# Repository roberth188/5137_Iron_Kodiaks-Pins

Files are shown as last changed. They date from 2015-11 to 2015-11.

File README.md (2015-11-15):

# 5137_Iron_Kodiaks-Pins
The team circuit board pins files, including both the schematic/board and Gerber files.
Contact me if you have any questions.

To order new boards, go to [dirtyPCBs](http://dirtypcbs.com/) and upload all of the Gerber files (the files that don't end in either .sch or .brd. Make sure to select 2 layer, the 5x5 cm size, the proper quantity, red color, 1.6mm thickness, ENIG Coating, no stencil, Regular processing, shipping to United States, and DHL China works very well. This will make the boards exactly like they were ordered before. 

Contact me about ordering the components - they vary considerably with what is in stock, so they will need to be found again.

Board file images were rendered with the fabulous ZofzPCB tool (available free online) and the colors were adjusted to accurately represent the ENIG plating over the pads of the red PCBS (for the team's cardinal and gold colors).

  

Yes, the trace that goes through the switch in that pad is unintentional but, as that connection is shorted, anyways, when it is turned off, it electrically has no impact. It can be safely and completely ignored.

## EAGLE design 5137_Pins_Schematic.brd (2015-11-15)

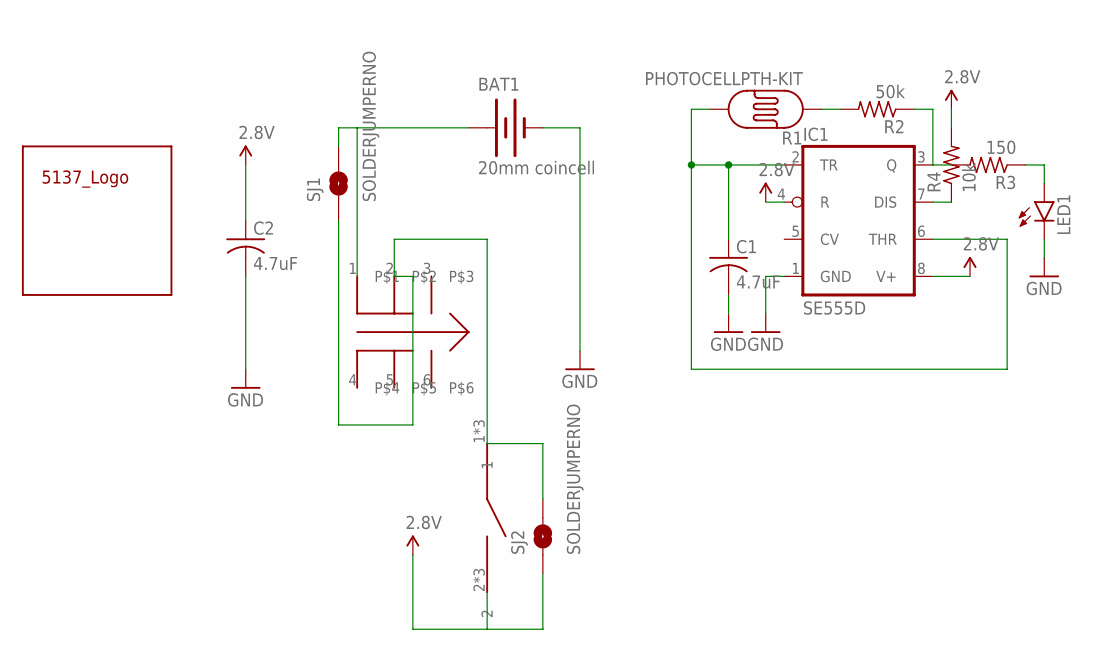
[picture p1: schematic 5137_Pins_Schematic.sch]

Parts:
BAT1: 20mm coincell; BATTCON_20MM_4LEGS
C1, C2: 4.7uF; C1206K
IC1: SE555D; SO08
LED1: LED5MM-KIT
R1: PHOTOCELLPTH-KIT; PHOTOCELL-KIT
R2: 50k; R1206W
R3: 150; R1206W
R4: 10k; R1206W
SJ1, SJ2: SOLDERJUMPERNO; SJ_2S-NO
U$1: 5137_LOGO_DEV; 5137_LOGO_PKG
U$2: SAFETY_PIN_SWITCH
U$3: DPDT_GULL_WING_SWITCH

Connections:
2.8V: C2.1, IC1.4 (R), IC1.8 (V+), R4.2, SJ2.1, U$2.2, U$2.2A (2), U$2.2B (2)
GND: BAT1.2 (-), C1.2, C2.2, IC1.1 (GND), LED1.K (C)
unnamed: IC1.3 (Q), R2.1, R3.2
unnamed: LED1.A, R3.1
unnamed: IC1.7 (DIS), R4.1
unnamed: R1.1, R2.2
unnamed: C1.1, IC1.2 (TR), IC1.6 (THR), R1.2
unnamed: BAT1.1 (+), SJ1.2, U$3.1
unnamed: SJ1.1, SJ2.2, U$2.1, U$2.1A (1), U$2.1B (1), U$3.2

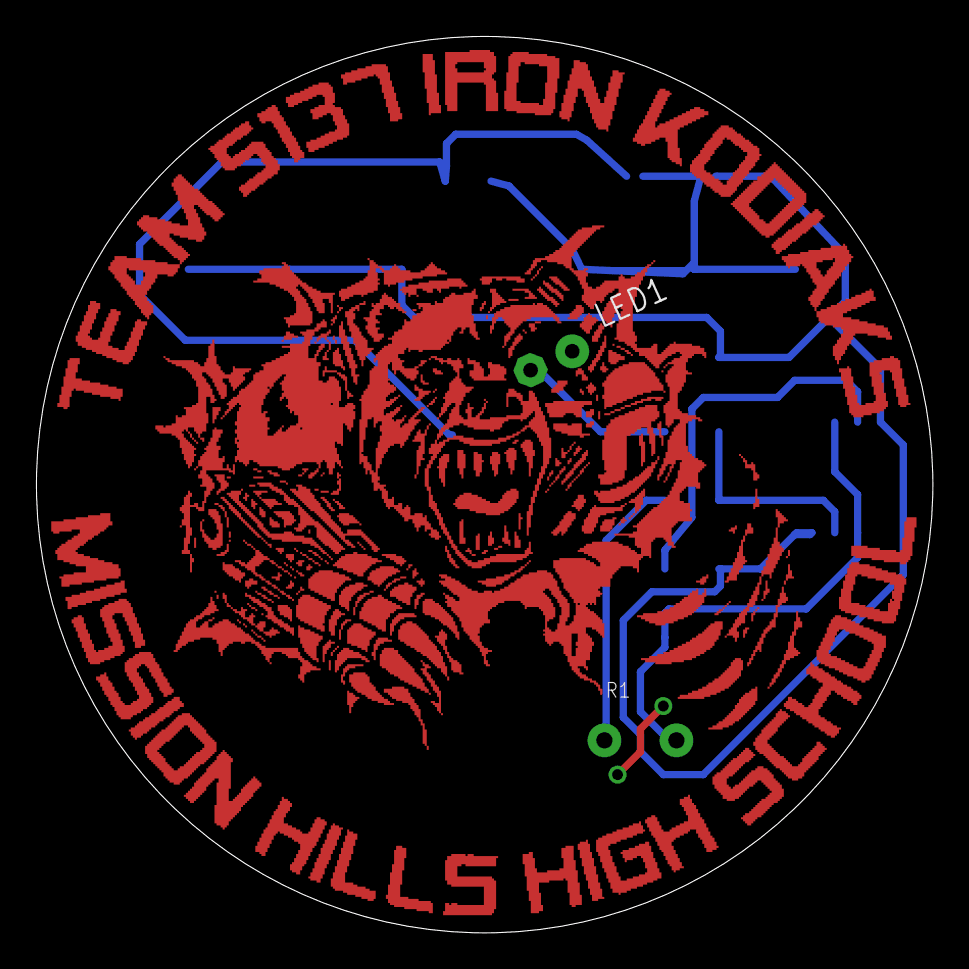
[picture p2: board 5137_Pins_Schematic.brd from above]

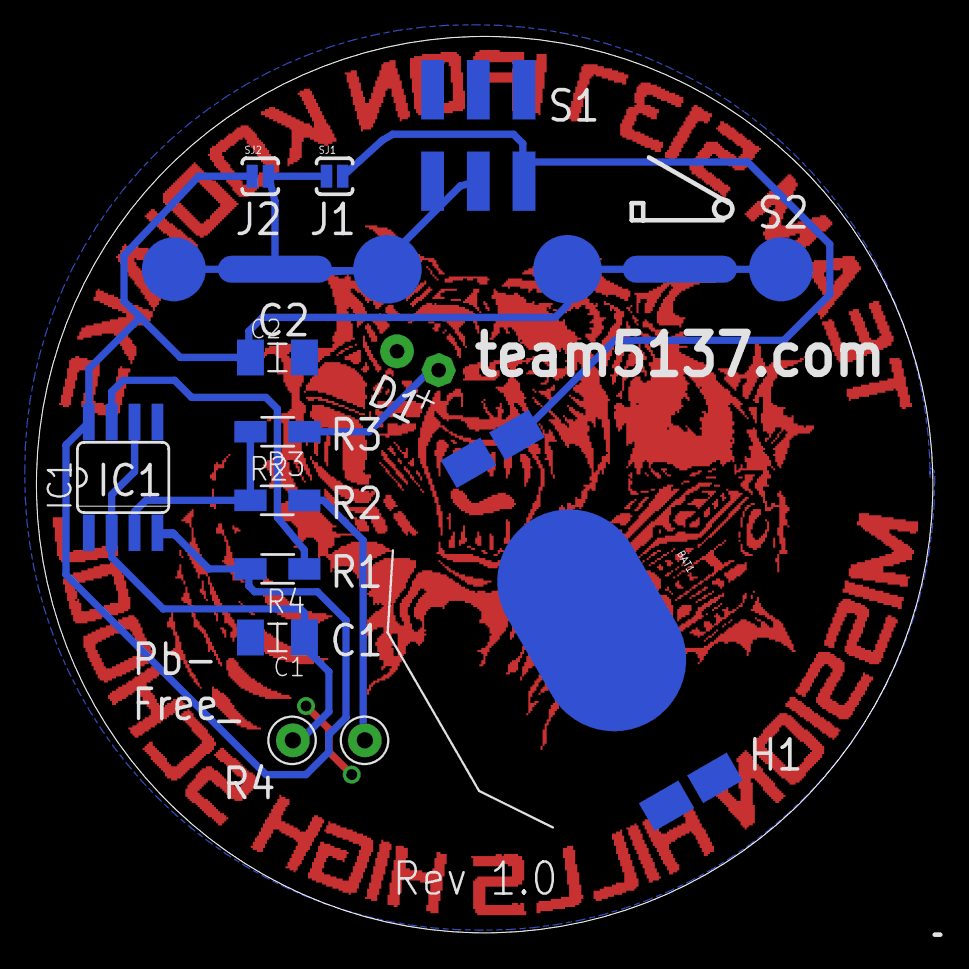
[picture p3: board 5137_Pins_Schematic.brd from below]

Board: 2 copper layers, 49.8 x 49.8 mm, 14 parts (11 on the bottom side), 9 nets.

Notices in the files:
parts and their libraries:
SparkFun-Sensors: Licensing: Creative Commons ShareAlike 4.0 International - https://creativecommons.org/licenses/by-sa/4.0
